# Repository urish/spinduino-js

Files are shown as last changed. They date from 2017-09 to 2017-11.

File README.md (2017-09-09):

# spinduino.js

BLE PoV Fidget Spinner

Copyright (C) 2017, Uri Shaked

Spinduino Prototype

[Hackaday project page](https://hackaday.io/project/27220/)

## Features

* JavaScript programmable 
* 10-Pixel RGB PoV display (using APA102 LEDs) 
* Spin count / speed detection using a magnetic latch 
* Bluetooth Low Energy (BLE) communication with smart phone / computer for controlling the display, reading the spin count and programming 
* Over-the-air firmware upgrades 
* Fully open-source

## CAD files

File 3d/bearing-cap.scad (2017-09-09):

// 608ZZ Bearing Cap with Magnet holes
// Copyright (C) 2017, Uri Shaked

$capHeight = 3;
$spacerHeight = 0.6;
$capRadius = 11;
$roundness = 0.5;
$magnetRadius = 1.25;

$fn = 60;

module rounded_cylinder(r,h,edge=0.2) {
    rotate_extrude() {
        hull() {
            square([r, h]);
            translate([r, edge])
            circle(edge);
            translate([r, h-edge])
            circle(edge);
        }
    }
}


translate([0,0,$capHeight+$spacerHeight])
difference() {
    union() {
        translate([0,0,2.4])
        rounded_cylinder(r=4.25,h=0.6);
        cylinder(r=4,h=2.4);
    }
    
    translate([-5,-0.4,0])
    cube([10,0.8,3]);
    
    rotate([0,0,90])
    translate([-5,-0.4,0])
    cube([10,0.8,3]);
}

translate([0,0,$capHeight])
cylinder(r=6,h=$spacerHeight);

difference() {
    rotate_extrude() {
        translate([0, $capHeight/2])
        square([4.2, $capHeight/2]);

        hull() {
            translate([0, 0])
            square([1, $capHeight]);
            
            translate([$capRadius, $roundness])
            scale([2,1])
            circle($roundness);
            
            translate([$capRadius, $capHeight-$roundness])
            
            circle($roundness);
        }
    }
    
    translate([0,$capRadius-$magnetRadius-0.25,1])
    cylinder(r=$magnetRadius,h=$capHeight+1);
    
    translate([$capRadius-$magnetRadius-0.25, 0,1])
    cylinder(r=$magnetRadius,h=$capHeight+1);
}

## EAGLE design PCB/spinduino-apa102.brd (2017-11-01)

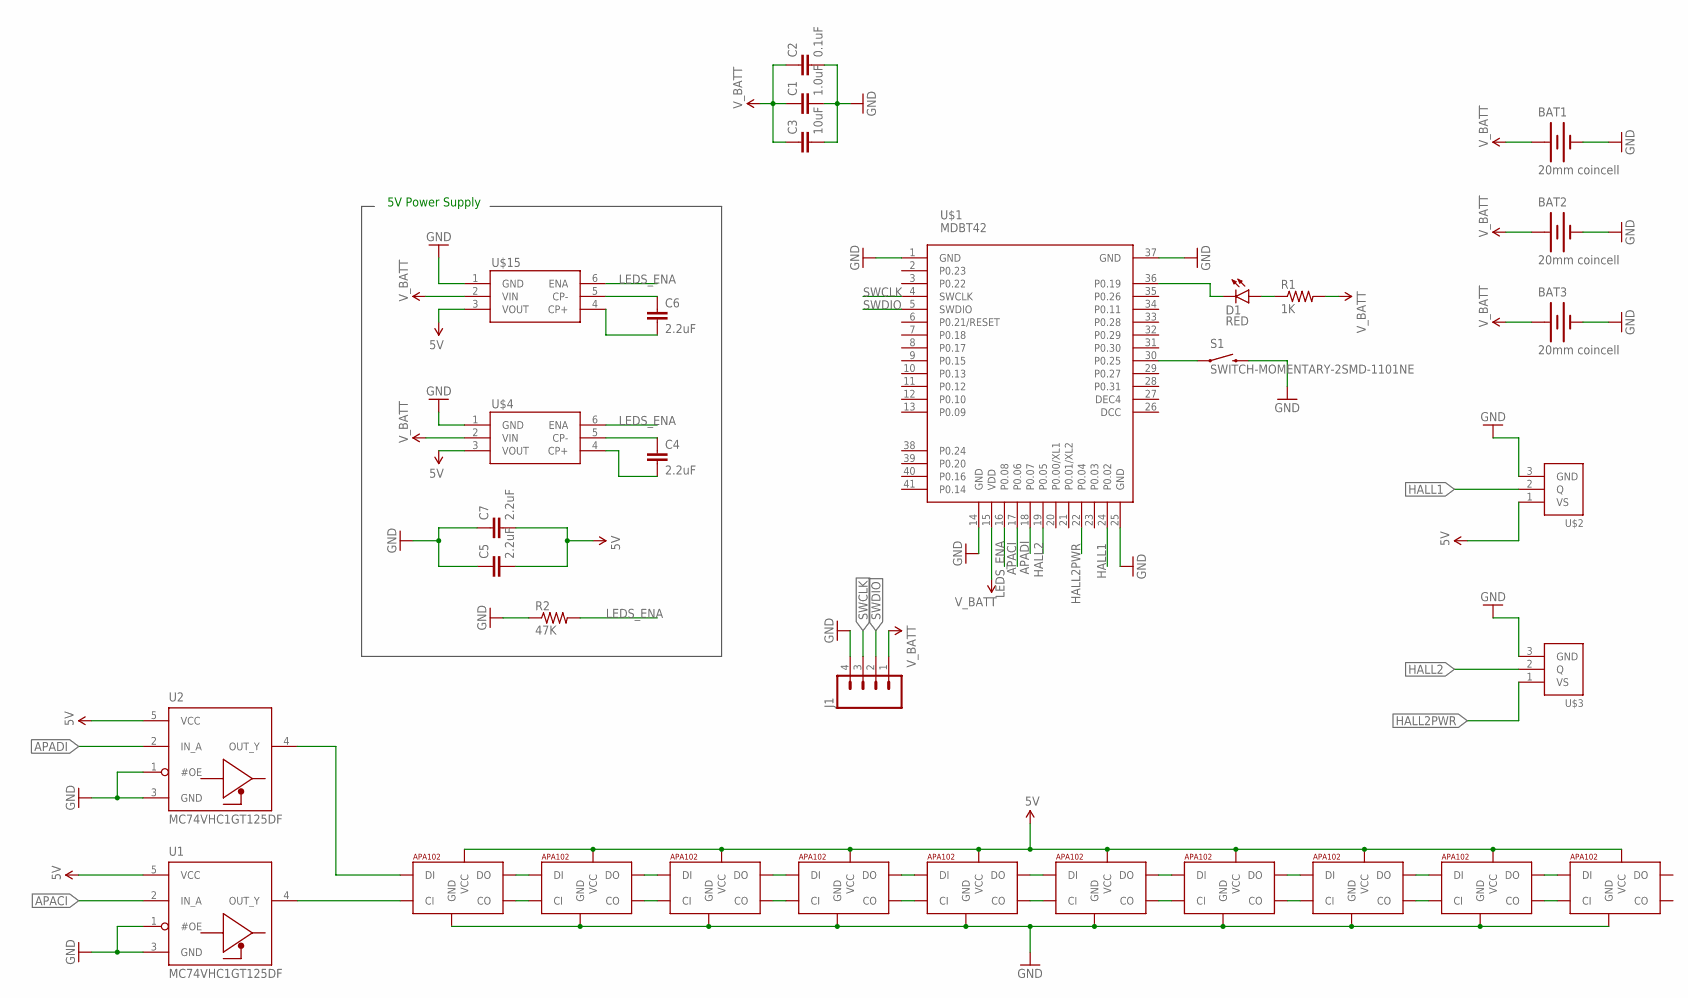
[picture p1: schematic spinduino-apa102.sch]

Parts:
BAT1, BAT2, BAT3: 20mm coincell; BATTCON_20MM_4LEGS
C1: 1.0uF; 0603-CAP
C2: 0.1uF; 0603-CAP
C3: 10uF; 0603-CAP
C4, C5, C6, C7: 2.2uF; 0603-CAP
D1: RED; LED-0603
J1: M04LOCK; 1X04_LOCK
R1: 1K; 0603-RES
R2: 47K; 0603-RES
S1: SWITCH-MOMENTARY-2SMD-1101NE; TACTILE-SWITCH-1101NE
U1, U2: MC74VHC1GT125DF; SOT353
U$1: MDBT42
U$2, U$3: TLE4946-2KSMD; SC-59
U$4, U$15: TPS60150; WSON6
U$5, U$6, U$7, U$8, U$9, U$10, U$11, U$12, U$13, U$14: APA1022020; APA102_2020

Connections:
5V: C5.2, C7.2, U1.5 (VCC), U2.5 (VCC), U$2.1 (VS), U$4.3 (VOUT), U$5.V_CC (VCC), U$6.V_CC (VCC), U$7.V_CC (VCC), U$8.V_CC (VCC), U$9.V_CC (VCC), U$10.V_CC (VCC), U$11.V_CC (VCC), U$12.V_CC (VCC), U$13.V_CC (VCC), U$14.V_CC (VCC), U$15.3 (VOUT)
APACI: U1.2 (IN_A), U$1.17 (P0.06)
APADI: U2.2 (IN_A), U$1.18 (P0.07)
GND: BAT1.NEGATIVE (-), BAT2.NEGATIVE (-), BAT3.NEGATIVE (-), C1.2, C2.2, C3.2, C5.1, C7.1, J1.4, R2.1, S1.2, U1.1 (#OE), U1.3 (GND), U2.1 (#OE), U2.3 (GND), U$1.1 (GND), U$1.14 (GND), U$1.25 (GND), U$1.37 (GND), U$2.3 (GND), U$3.3 (GND), U$4.1 (GND), U$5.GND, U$6.GND, U$7.GND, U$8.GND, U$9.GND, U$10.GND, U$11.GND, U$12.GND, U$13.GND, U$14.GND, U$15.1 (GND)
HALL1: U$1.24 (P0.02), U$2.2 (Q)
HALL2: U$1.19 (P0.05), U$3.2 (Q)
HALL2PWR: U$1.22 (P0.04), U$3.1 (VS)
LEDS_ENA: R2.2, U$1.16 (P0.08), U$4.6 (ENA), U$15.6 (ENA)
unnamed: U$10.C_IN (CI), U$11.CL_OUT (CO)
unnamed: U$10.D_IN (DI), U$11.D_OUT (DO)
unnamed: D1.C, U$1.36 (P0.19)
unnamed: D1.A, R1.1
unnamed: U$5.D_IN (DI), U$6.D_OUT (DO)
unnamed: U$5.C_IN (CI), U$6.CL_OUT (CO)
unnamed: U$6.D_IN (DI), U$7.D_OUT (DO)
unnamed: U$6.C_IN (CI), U$7.CL_OUT (CO)
unnamed: U$7.D_IN (DI), U$8.D_OUT (DO)
unnamed: U$7.C_IN (CI), U$8.CL_OUT (CO)
unnamed: U$8.D_IN (DI), U$9.D_OUT (DO)
unnamed: U$8.C_IN (CI), U$9.CL_OUT (CO)
unnamed: U$9.D_IN (DI), U$10.D_OUT (DO)
unnamed: U$9.C_IN (CI), U$10.CL_OUT (CO)
unnamed: U$11.D_IN (DI), U$12.D_OUT (DO)
unnamed: U$11.C_IN (CI), U$12.CL_OUT (CO)
unnamed: U$12.D_IN (DI), U$13.D_OUT (DO)
unnamed: U$12.C_IN (CI), U$13.CL_OUT (CO)
unnamed: U$13.D_IN (DI), U$14.D_OUT (DO)
unnamed: U$13.C_IN (CI), U$14.CL_OUT (CO)
unnamed: S1.1, U$1.30 (P0.25)
unnamed: C4.2, U$4.4 (CP+)
unnamed: C4.1, U$4.5 (CP-)
unnamed: U2.4 (OUT_Y), U$14.D_IN (DI)
unnamed: U1.4 (OUT_Y), U$14.C_IN (CI)
unnamed: C6.1, U$15.5 (CP-)
unnamed: C6.2, U$15.4 (CP+)
SWCLK: J1.3, U$1.4 (SWCLK)
SWDIO: J1.2, U$1.5 (SWDIO)
V_BATT: BAT1.POSITIVE@1 (+), BAT1.POSITIVE@2 (+), BAT1.POSITIVE@3 (+), BAT1.POSITIVE@4 (+), BAT2.POSITIVE@1 (+), BAT2.POSITIVE@2 (+), BAT2.POSITIVE@3 (+), BAT2.POSITIVE@4 (+), BAT3.POSITIVE@1 (+), BAT3.POSITIVE@2 (+), BAT3.POSITIVE@3 (+), BAT3.POSITIVE@4 (+), C1.1, C2.1, C3.1, J1.1, R1.2, U$1.15 (VDD), U$4.2 (VIN), U$15.2 (VIN)

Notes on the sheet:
5V Power Supply

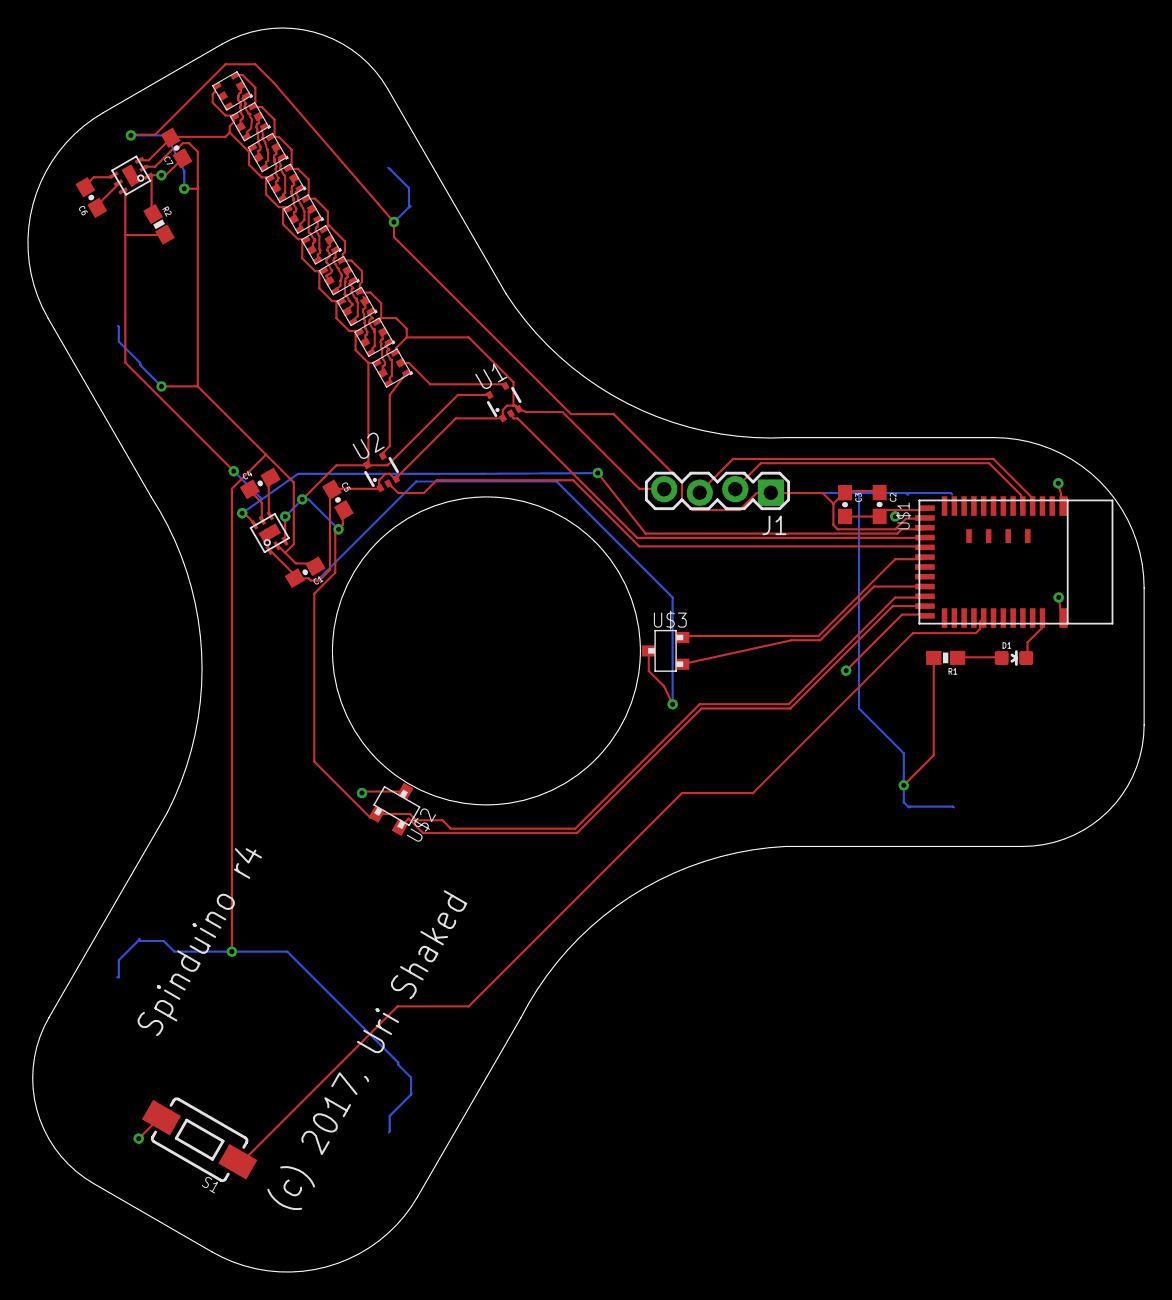
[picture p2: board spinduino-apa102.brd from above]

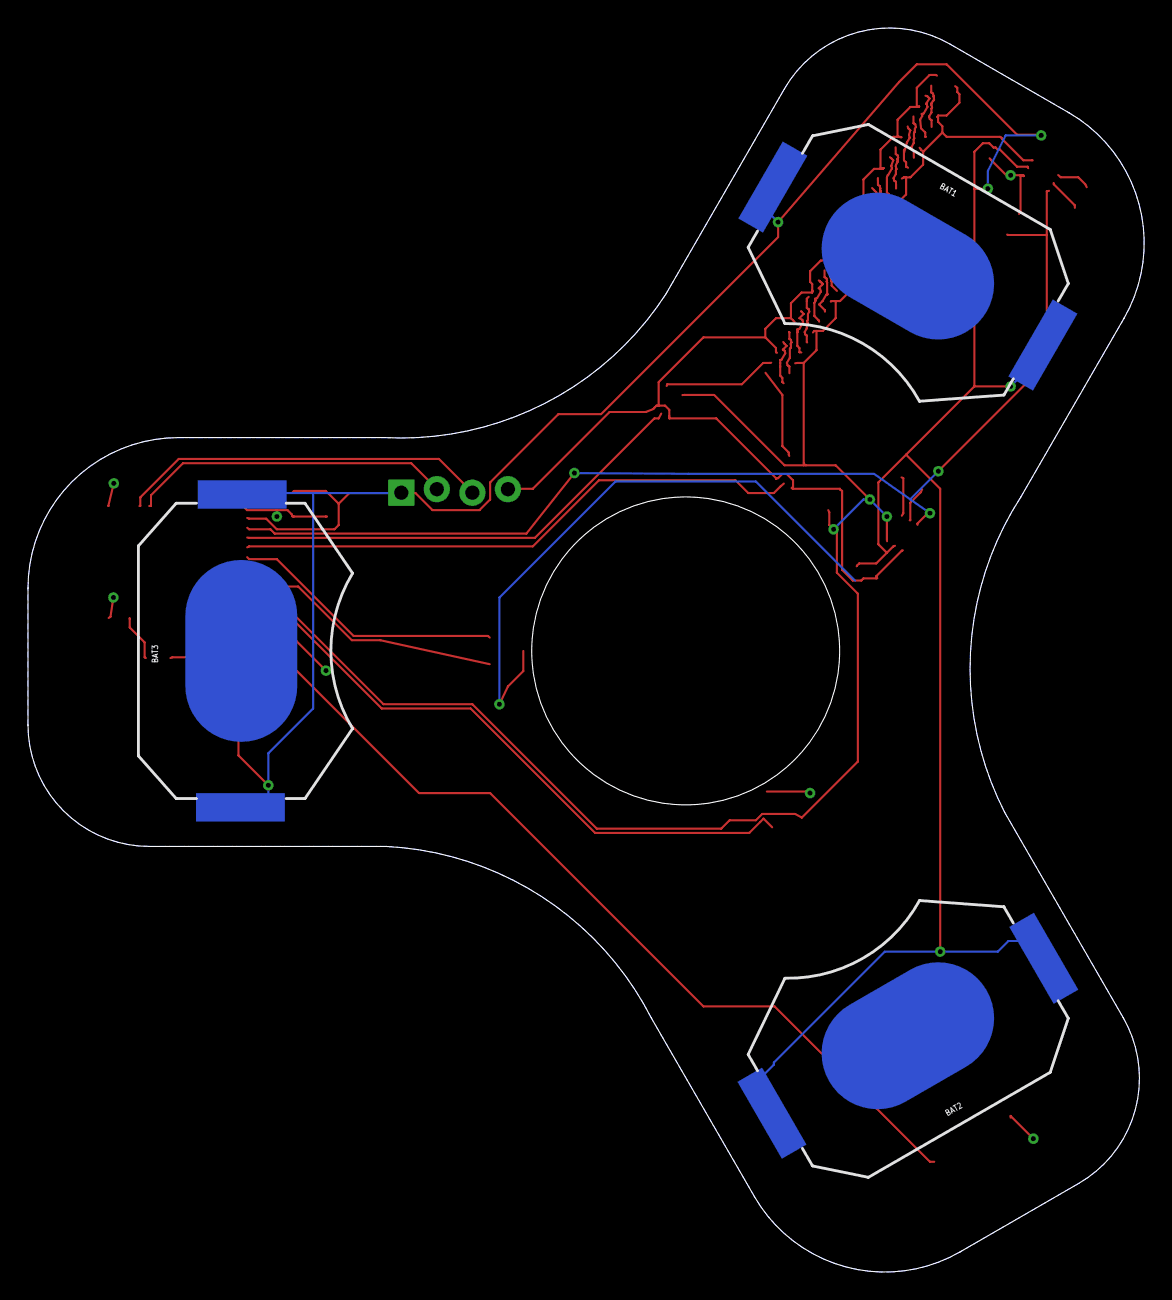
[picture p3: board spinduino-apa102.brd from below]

Board: 2 copper layers, 79.7 x 88.9 mm, 32 parts (3 on the bottom side), 38 nets.

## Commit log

2017-07-31 add programming connector
    [spinduino.brd, spinduino.sch]
2017-08-01 add APA102-2020 variant
    [spinduino-apa102.brd, spinduino-apa102.sch]
2017-08-23 add bearing cap scad file
    [bearing-cap.scad]
2017-08-23 fix: remove redundant resistor
    [spinduino-apa102.brd, spinduino-apa102.sch]
2017-09-08 Make hall effect sensors powered by CPU
    This will help with standby power consumption
    [spinduino-apa102.brd, spinduino-apa102.sch]
2017-09-08 reduce inner hole diameter
    [spinduino-apa102.brd]
2017-09-08 update board revision number
    [spinduino-apa102.brd]
2017-09-09 fix: make spinner symetrical
    [spinduino-apa102.brd]
2017-09-09 cleanup: remove old spinduino files
    [spinduino.brd, spinduino.sch]
2017-09-09 feat: ground plane on bottom layer
    [spinduino-apa102.brd]
2017-09-09 improve bearing cap
    [bearing-cap.scad]
2017-09-09 feat: powed the LEDs by 5V pump
    [spinduino-apa102.brd, spinduino-apa102.sch]
2017-09-09 fix: cover vias with solder mask
    [spinduino-apa102.brd]
2017-09-27 fix a few issues in board:
    1. remove copper under antenna
    2. fix wrong pin assignments of TPS60150
    3. shrink inner hole a bit
    4. fix package for MC74VHC1GT125 (SOT353 instead of SOT23-5)
    5. move text to a different wing
    [spinduino-apa102.brd, spinduino-apa102.sch]
2017-10-01 fix: add pull-down resistor for the TPS60150 enable pin
    [spinduino-apa102.brd, spinduino-apa102.sch]
2017-10-01 fix: update revision number (4)
    [spinduino-apa102.brd]
2017-10-29 fix: use D2 hall sensor instead of D5
2017-10-29 fix: Remove APA text from silk screen
    [spinduino-apa102.brd]
2017-10-29 fix: connect one of the hall effect sensors to the 5v power supply
    [spinduino-apa102.brd, spinduino-apa102.sch]
2017-11-01 fix: rotate the APA 102 LEDs
    So the red / green / blue are aligned (more or less)
    [spinduino-apa102.brd]

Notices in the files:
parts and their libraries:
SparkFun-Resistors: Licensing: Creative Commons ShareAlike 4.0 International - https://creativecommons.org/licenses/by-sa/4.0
